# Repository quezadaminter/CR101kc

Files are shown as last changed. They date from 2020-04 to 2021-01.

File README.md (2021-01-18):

# CR101kc
The electrical schematics and PCB layout for the CR101 boards.  

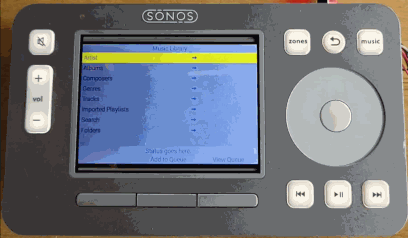
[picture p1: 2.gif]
  

# Firmware  
https://github.com/quezadaminter/CR101fw  

# User code  
https://github.com/quezadaminter/CR101py  

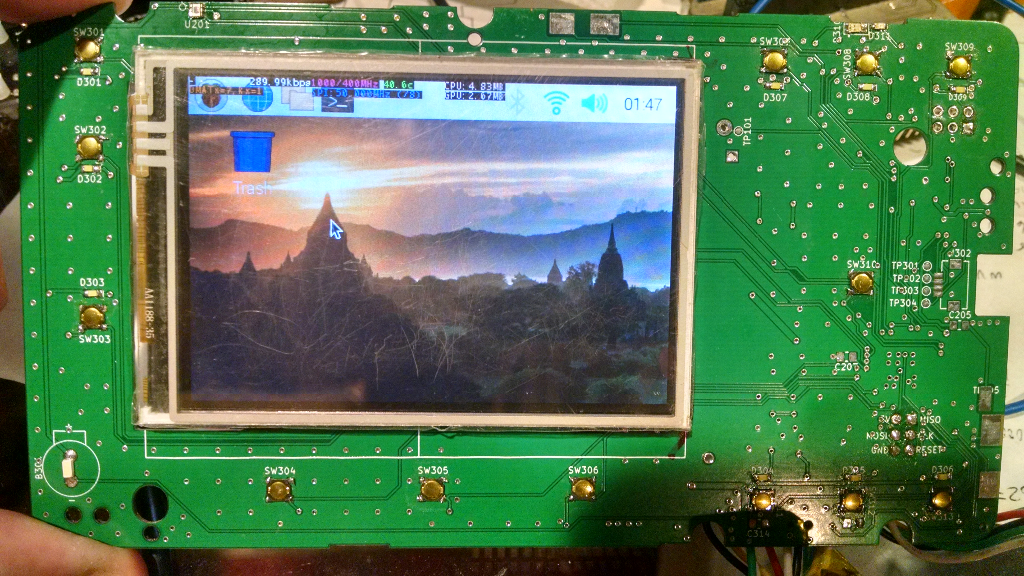
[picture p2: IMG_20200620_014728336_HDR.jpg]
  
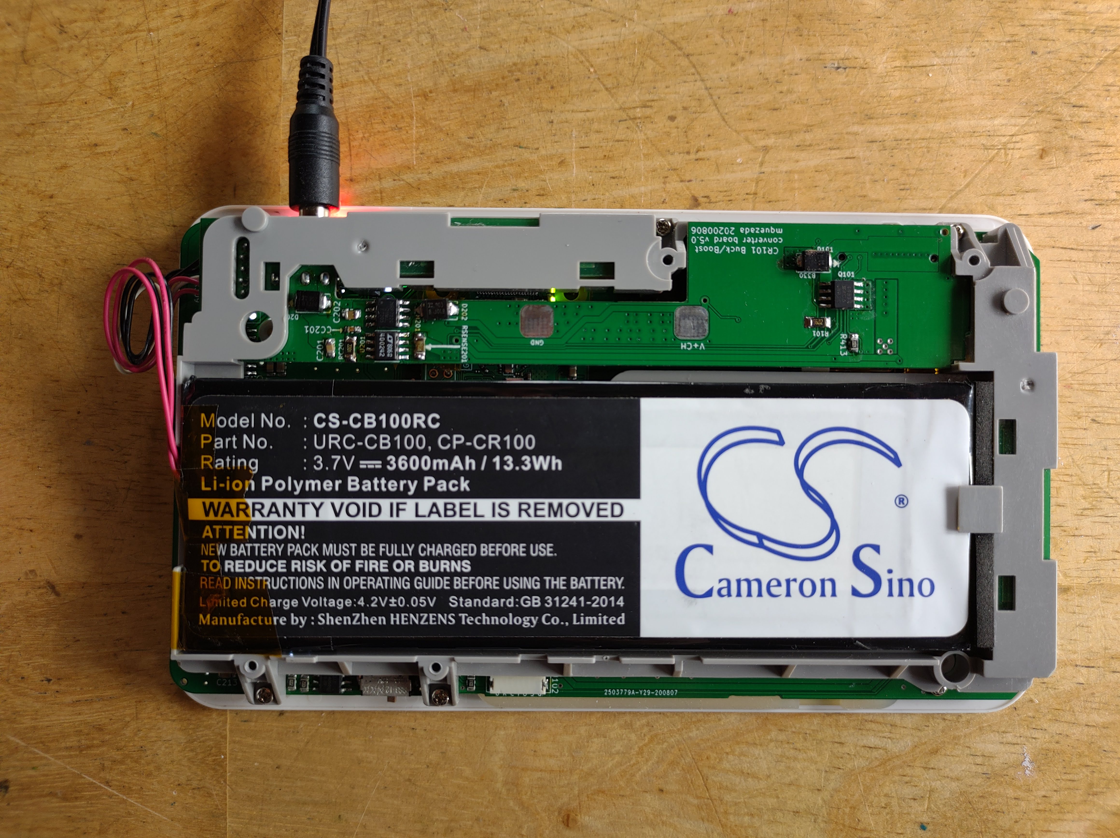
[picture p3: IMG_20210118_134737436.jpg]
  
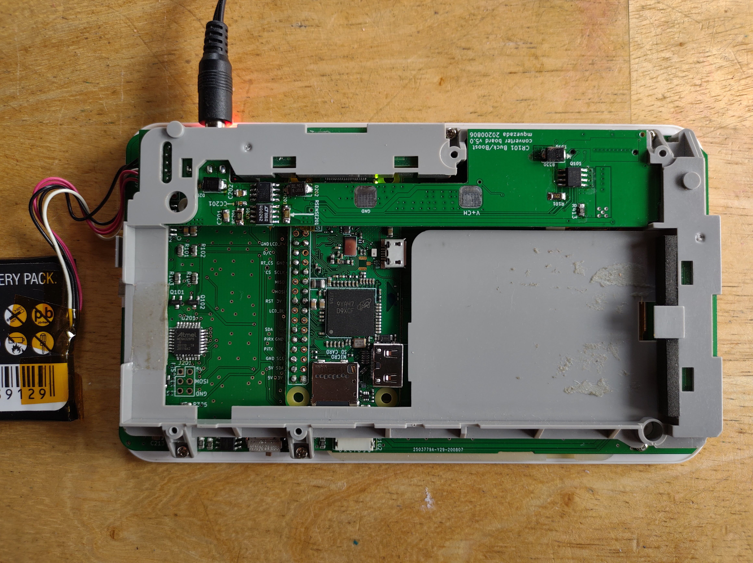
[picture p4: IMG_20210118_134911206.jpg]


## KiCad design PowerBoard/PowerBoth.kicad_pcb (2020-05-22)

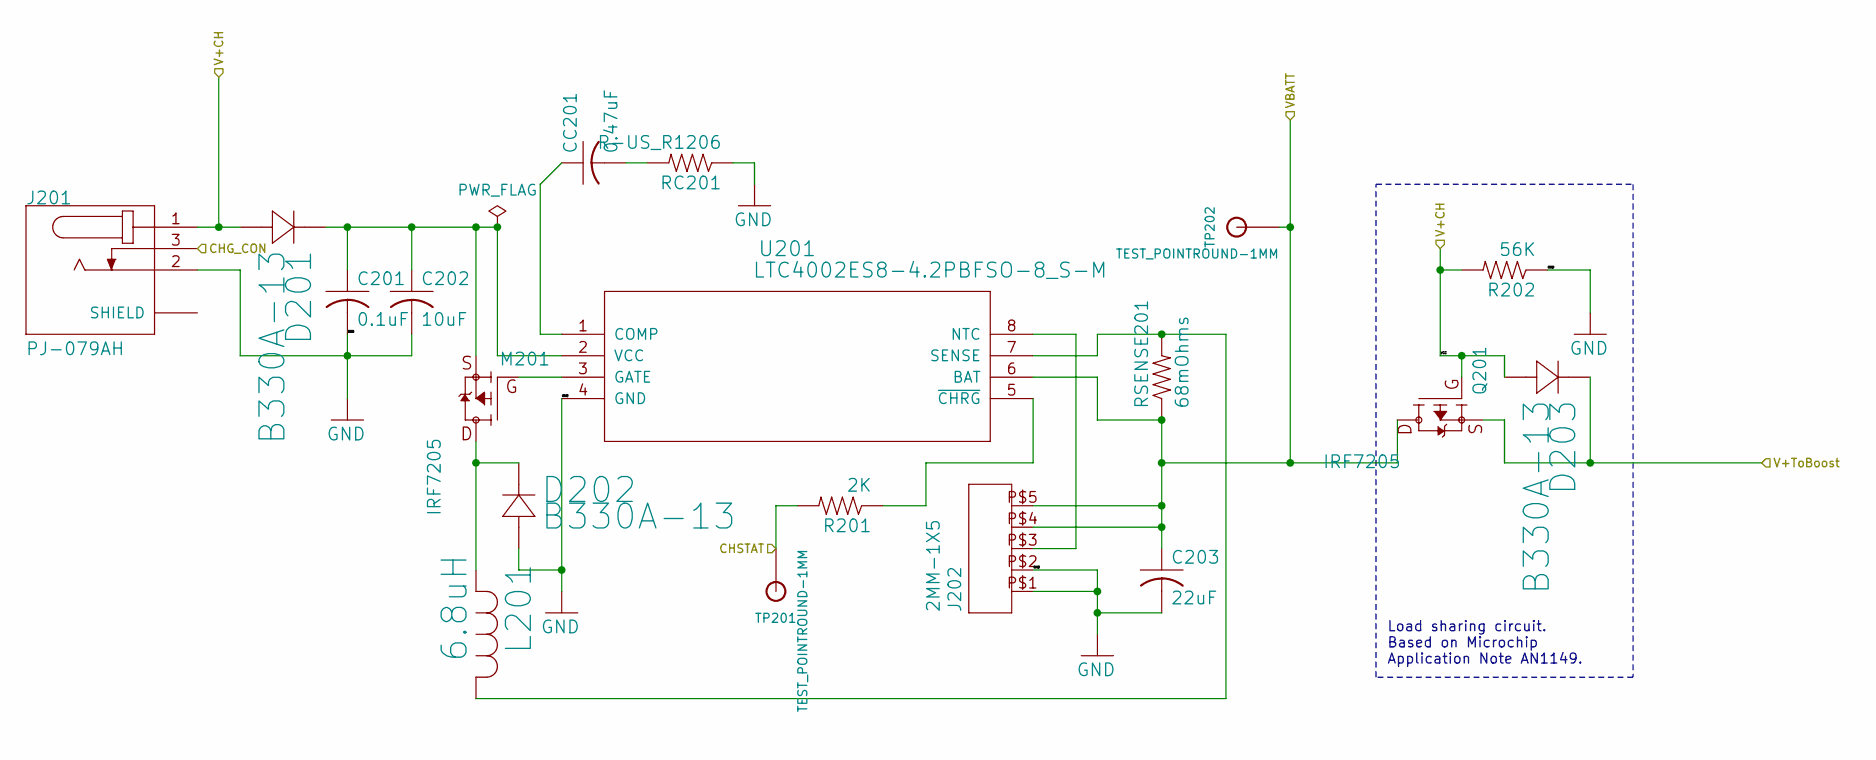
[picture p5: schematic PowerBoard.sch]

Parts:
C201: 0.1uF; C1210; LCSC Part Number 1
C202: 10uF; C1210
C203: 22uF; C1210
CC201: 0.47uF; C0603
D201, D202, D203: B330A-13; SMA-M
J201: PJ-079AH; CUI_PJ-079AH
J202: 2MM-1X5; 2MM_1X5
L201: 6.8uH; IND_B952AS-H-220M=P3
M201: IRF7205; 8SOIC; LCSC Part Number C55419
Q201: IRF7205; 8SOIC; LCSC Part Number C55419
R201: 2K; R1206
R202: 56K; 1206
RC201: R-US_R1206; R1206
RSENSE201: 68mOhms; R1206
TP201, TP202: TEST_POINTROUND-1MM; TEST_POINT_ROUND_1MM
U201: LTC4002ES8-4.2PBFSO-8_S-M; SO-8_S-M

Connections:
/Charger/CHG_CON: J201.3; also elsewhere on the board
/Charger/CHSTAT: R201.2, TP201.1; also elsewhere on the board
/Charger/V+CH: D201.2, D203.2, J201.1, Q201.4 (G), R202.2; also elsewhere on the board
/Charger/V+ToBoost: D203.1, Q201.1 (S), Q201.2 (S), Q201.3 (S); also elsewhere on the board
/Charger/VBATT: C203.1, J202.P$4, J202.P$5, Q201.5 (D), Q201.6 (D), Q201.7 (D), Q201.8 (D), RSENSE201.1, TP202.1, U201.6 (BAT); also elsewhere on the board
GND: C201.2, C202.2, C203.2, D202.2, J201.2, J202.P$1, J202.P$2, R202.1, RC201.1, U201.4 (GND); also elsewhere on the board
unnamed: C201.1, C202.1, D201.1, M201.1 (S), M201.2 (S), M201.3 (S), U201.2 (VCC)
unnamed: CC201.1, U201.1 (COMP)
unnamed: CC201.2, RC201.2
unnamed: D202.1, L201.2, M201.5 (D), M201.6 (D), M201.7 (D), M201.8 (D)
unnamed: J201.S1 (SHIELD), J201.S2 (SHIELD)
unnamed: J202.P$3, U201.8 (NTC)
unnamed: L201.1, RSENSE201.2, U201.7 (SENSE)
unnamed: M201.4 (G), U201.3 (GATE)
unnamed: R201.1, U201.5 (~CHRG)

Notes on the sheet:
Load sharing circuit. Based on Microchip Application Note AN1149.

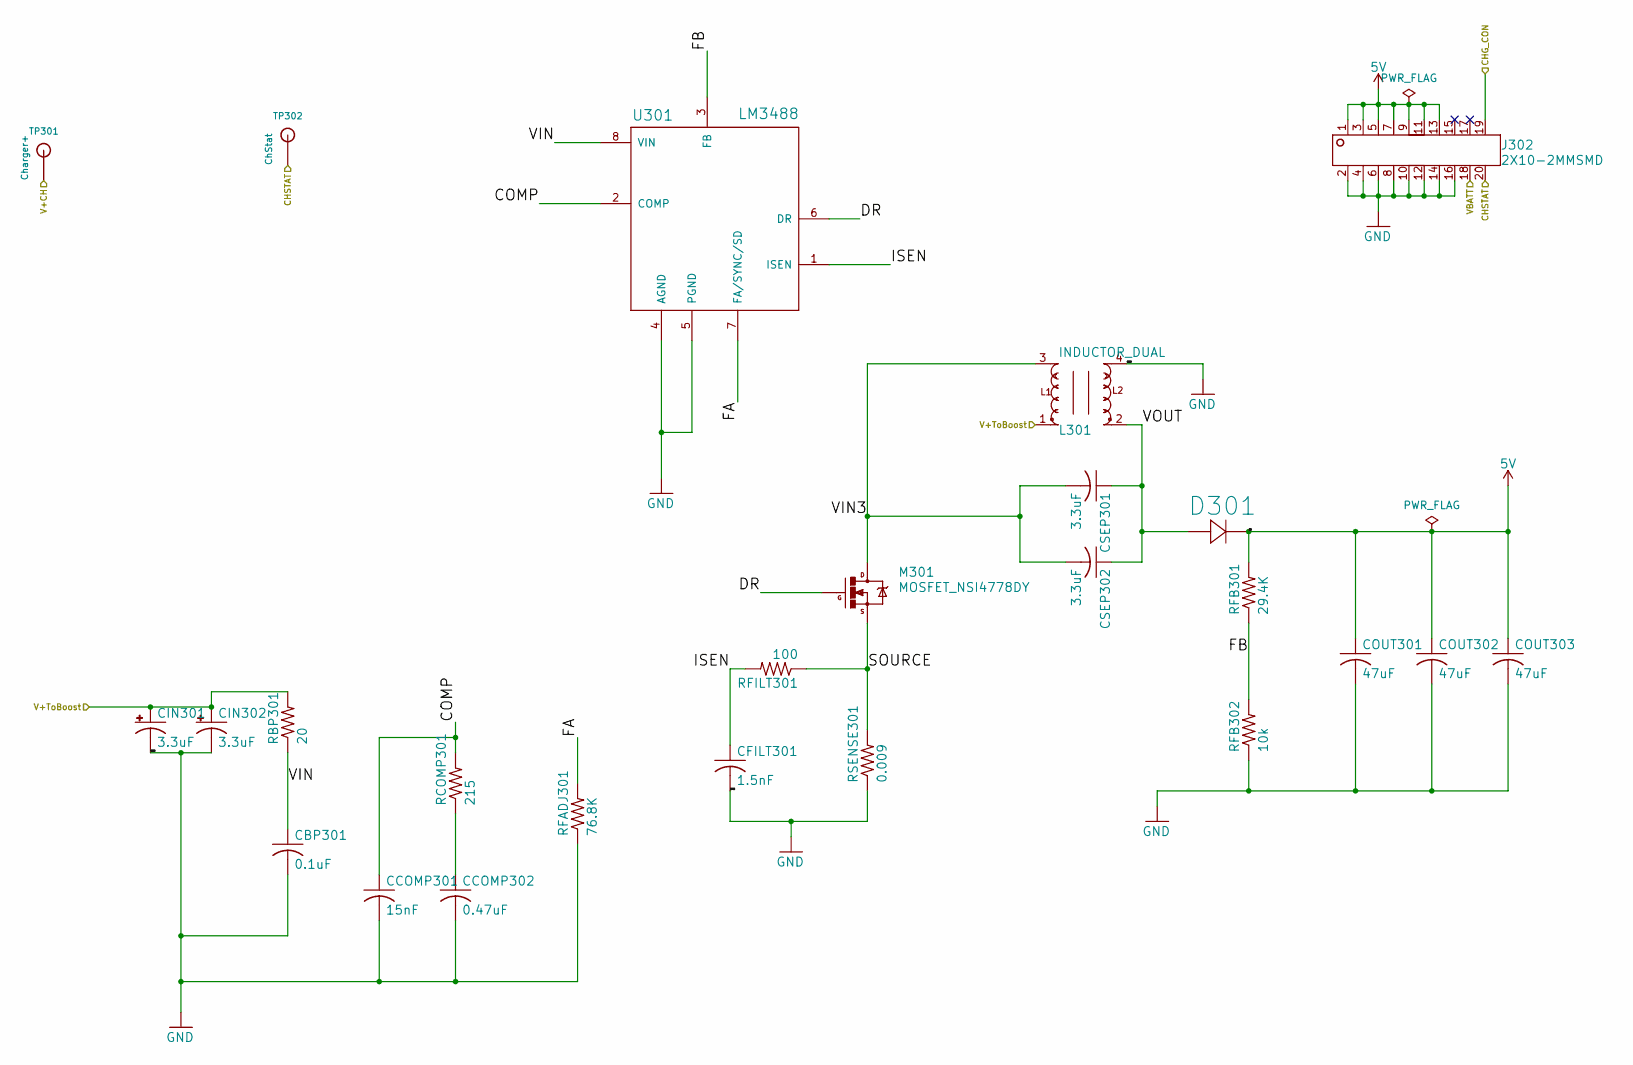
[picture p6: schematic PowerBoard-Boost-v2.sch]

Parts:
CBP301: 0.1uF; C1206
CCOMP301: 15nF; C0805
CCOMP302: 0.47uF; C1206
CFILT301: 1.5nF; C0805
CIN301, CIN302: 3.3uF; 153CLV-0505
COUT301, COUT302, COUT303: 47uF; C1206
CSEP301, CSEP302: 3.3uF; C0805
D301: SL44-E3_57TDIODE_DO214AB-M; DIODE_DO214AB-M
J302: 2X10-2MMSMD; 2X10-2MM
L301: INDUCTOR_DUAL; DRQ125
M301: MOSFET_NSI4778DY; 8SOIC
RBP301: 20; R0805
RCOMP301: 215; R0805
RFADJ301: 76.8K; R0805
RFB301: 29.4K; R1206
RFB302: 10k; R1206
RFILT301: 100; R1206
RSENSE301: 0.009; R1206
TP301: Charger+; TEST_POINT_ROUND_1MM
TP302: ChStat; TEST_POINT_ROUND_1MM
U301: LM3488; DGK8-M

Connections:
5V: COUT301.1, COUT302.1, COUT303.1, D301.1, J302.1, J302.3, J302.5, J302.7, J302.9, J302.11, J302.13, RFB301.2
/Charger/CHG_CON: J302.19; also elsewhere on the board
/Charger/CHSTAT: J302.20, TP302.1; also elsewhere on the board
/Charger/V+CH: TP301.1; also elsewhere on the board
/Charger/V+ToBoost: CIN301.+, CIN302.+, L301.1, RBP301.2; also elsewhere on the board
/Charger/VBATT: J302.18; also elsewhere on the board
/SEPIC Converter/COMP: CCOMP301.1, RCOMP301.2, U301.2 (COMP)
/SEPIC Converter/DR: M301.4 (G), U301.6 (DR)
/SEPIC Converter/FA: RFADJ301.2, U301.7 (FA/SYNC/SD)
/SEPIC Converter/FB: RFB301.1, RFB302.2, U301.3 (FB)
/SEPIC Converter/ISEN: CFILT301.1, RFILT301.2, U301.1 (ISEN)
/SEPIC Converter/SOURCE: M301.1 (S), M301.2 (S), M301.3 (S), RFILT301.1, RSENSE301.2
/SEPIC Converter/VIN: CBP301.1, RBP301.1, U301.8 (VIN)
/SEPIC Converter/VIN3: CSEP301.2, CSEP302.2, L301.3, M301.5 (D), M301.6 (D), M301.7 (D), M301.8 (D)
/SEPIC Converter/VOUT: CSEP301.1, CSEP302.1, D301.2, L301.2
GND: CBP301.2, CCOMP301.2, CCOMP302.2, CFILT301.2, CIN301.-, CIN302.-, COUT301.2, COUT302.2, COUT303.2, J302.2, J302.4, J302.6, J302.8, J302.10, J302.12, J302.14, J302.16, L301.4, RFADJ301.1, RFB302.1, RSENSE301.1, U301.4 (AGND), U301.5 (PGND); also elsewhere on the board
unnamed: CCOMP302.1, RCOMP301.1

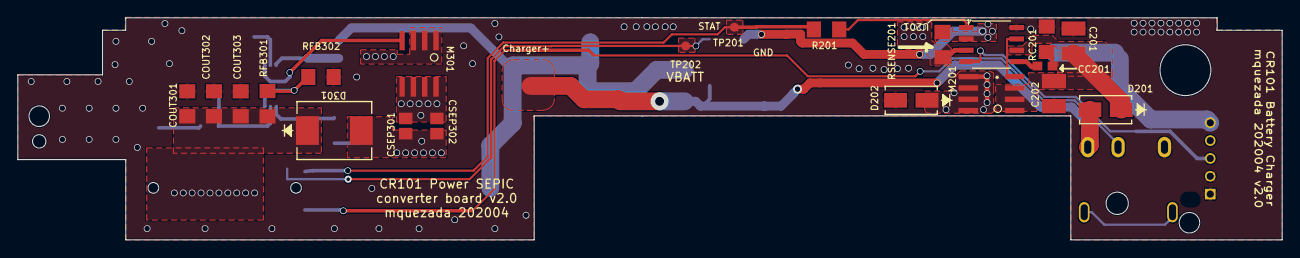
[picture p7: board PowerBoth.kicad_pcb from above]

Board: 2 copper layers, 141.8 x 24.9 mm, 48 parts (0 on the bottom side), 26 nets.

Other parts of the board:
@HOLE0, @HOLE1, @HOLE2, @HOLE3, @HOLE4: (no value)

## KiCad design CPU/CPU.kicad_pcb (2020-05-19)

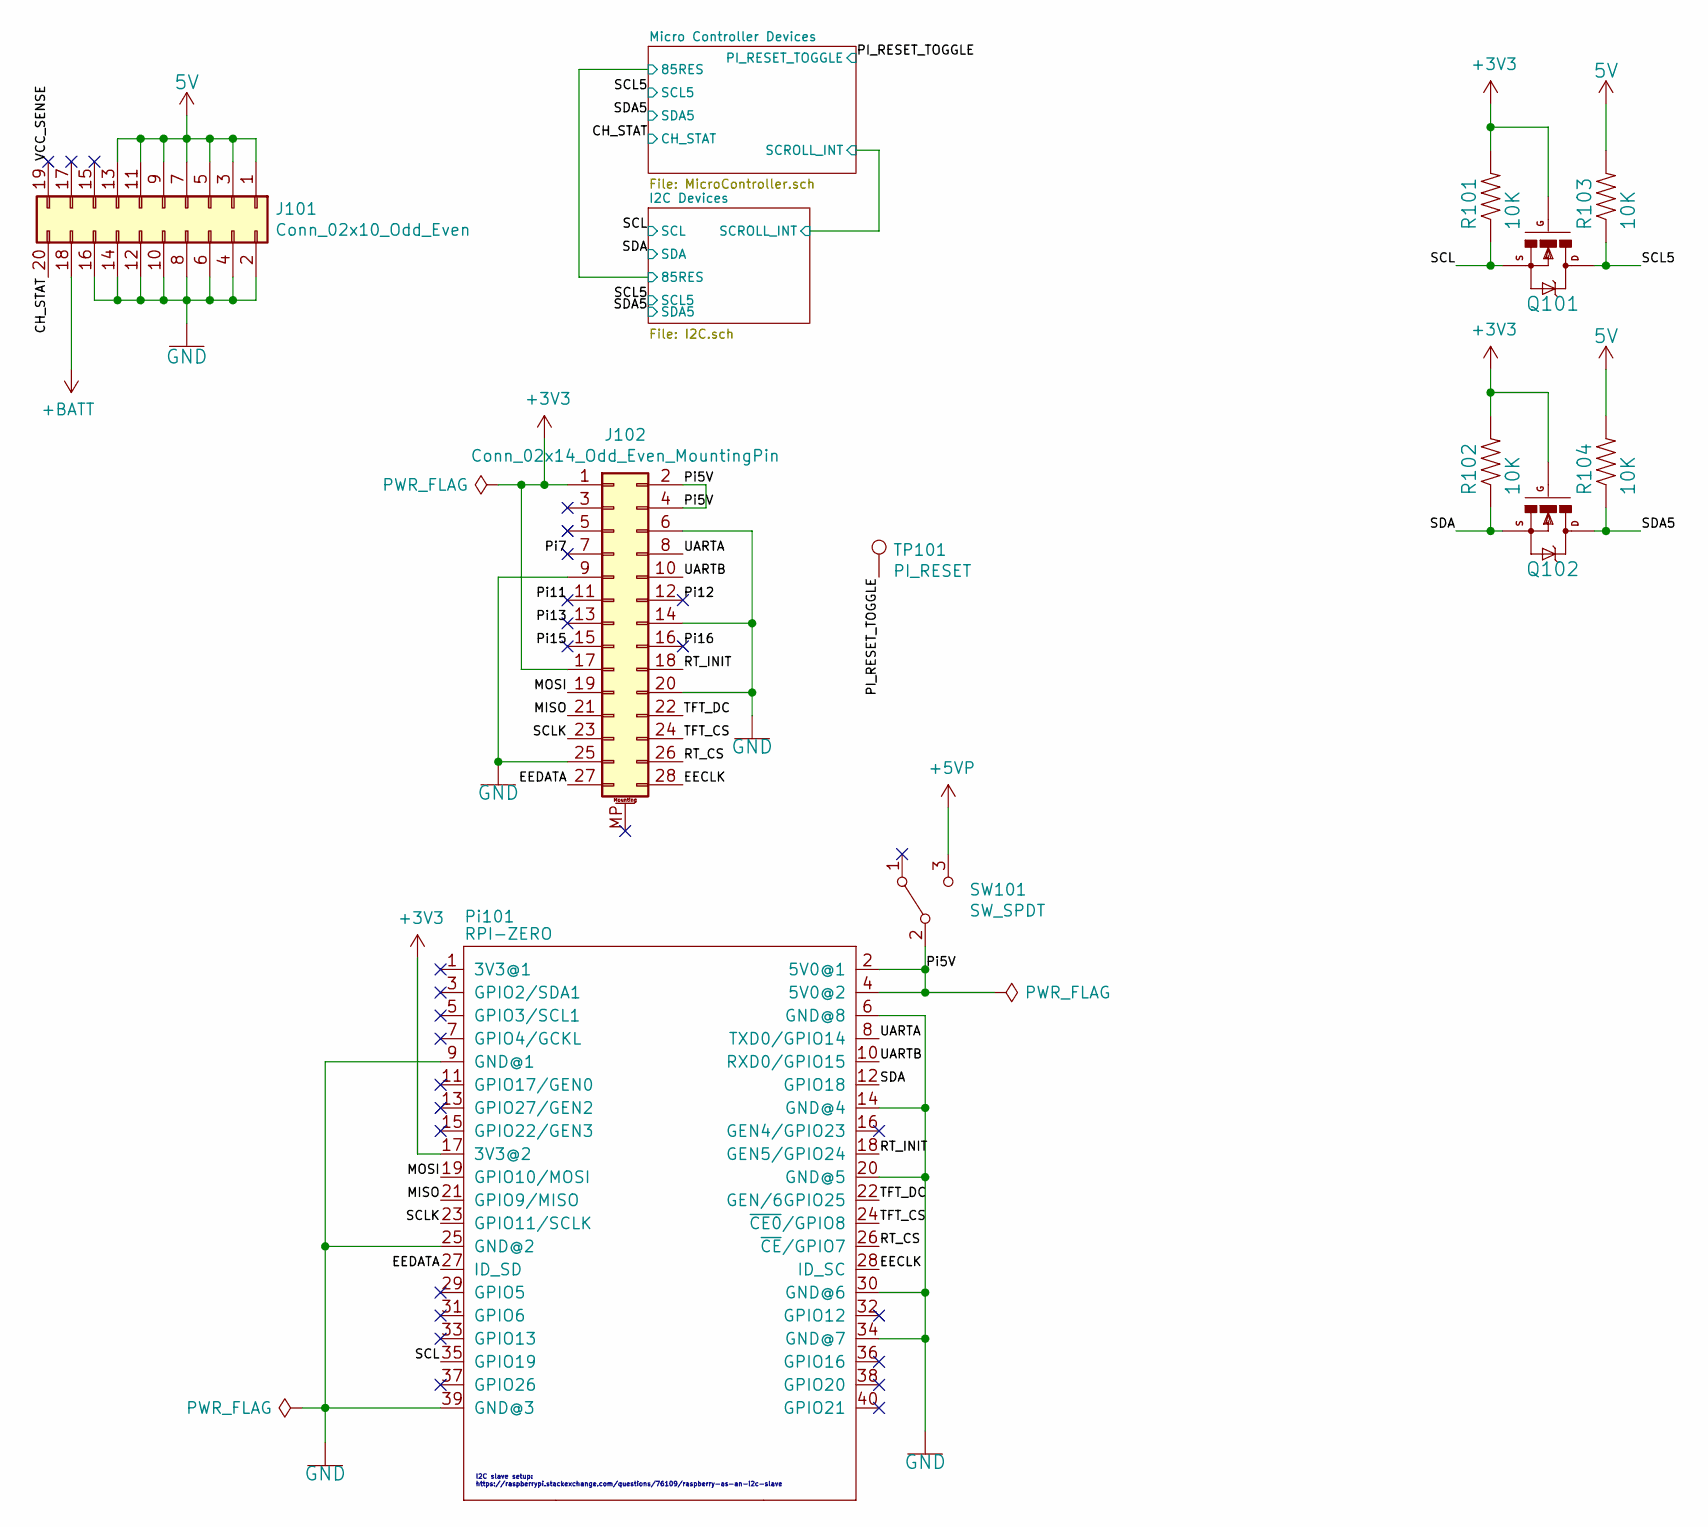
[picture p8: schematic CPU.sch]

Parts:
J101: Conn_02x10_Odd_Even; PinHeader_2x10_P2.00mm_Vertical_SMD; LCSC Part Number C135211
J102: Conn_02x14_Odd_Even_MountingPin; 2X14_SMT_MALE-2
Pi101: RPI-ZERO; RASPBERRYPI_Zero-No_Mounting_Holes_SMD_Flat
Q101, Q102: IRLML0040TR; SOT23; LCSC Part Number C67273
R101, R102, R103, R104: 10K; R_0805_2012Metric_Pad1.15x1.40mm_HandSolder; LCSC Part Number C17414
SW101: SW_SPDT; SWITCH_PCM12SMTR_SPDT; LCSC Part Number C221841
TP101: PI_RESET; TestPoint_Pad_D1.0mm

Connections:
5V: J101.1, J101.3, J101.5, J101.7, J101.9, J101.11, J101.13, R103.2, R104.2; also elsewhere on the board
+3V3: J102.1, J102.17, Pi101.17 (3V3@2), Q101.1 (G), Q102.1 (G), R101.2, R102.2; also elsewhere on the board
+5VP: SW101.3 (C); also elsewhere on the board
+BATT: J101.18; also elsewhere on the board
/CH_STAT: J101.20; also elsewhere on the board
/EECLK: J102.28, Pi101.28 (ID_SC)
/EEDATA: J102.27, Pi101.27 (ID_SD)
/MISO: J102.21, Pi101.21 (GPIO9/MISO)
/MOSI: J102.19, Pi101.19 (GPIO10/MOSI)
/PI_RESET_TOGGLE: TP101.1; also elsewhere on the board
/Pi5V: J102.2, J102.4, Pi101.2 (5V0@1), Pi101.4 (5V0@2), SW101.2 (B)
/Pi7: J102.7
/Pi11: J102.11
/Pi12: J102.12
/Pi13: J102.13
/Pi15: J102.15
/Pi16: J102.16
/RT_CS: J102.26, Pi101.26 (~CE~/GPIO7)
/RT_INIT: J102.18, Pi101.18 (GEN5/GPIO24)
/SCL: Pi101.35 (GPIO19), Q101.2 (S), R101.1; also elsewhere on the board
/SCL5: Q101.3 (D), R103.1; also elsewhere on the board
/SCLK: J102.23, Pi101.23 (GPIO11/SCLK)
/SDA: Pi101.12 (GPIO18), Q102.2 (S), R102.1; also elsewhere on the board
/SDA5: Q102.3 (D), R104.1; also elsewhere on the board
/TFT_CS: J102.24, Pi101.24 (~CE0~/GPIO8)
/TFT_DC: J102.22, Pi101.22 (GEN/6GPIO25)
/UARTA: J102.8, Pi101.8 (TXD0/GPIO14)
/UARTB: J102.10, Pi101.10 (RXD0/GPIO15)
/VCC_SENSE: J101.19
GND: J101.2, J101.4, J101.6, J101.8, J101.10, J101.12, J101.14, J101.16, J102.6, J102.9, J102.14, J102.20, J102.25, Pi101.6 (GND@8), Pi101.9 (GND@1), Pi101.14 (GND@4), Pi101.20 (GND@5), Pi101.25 (GND@2), Pi101.30 (GND@6), Pi101.34 (GND@7), Pi101.39 (GND@3); also elsewhere on the board

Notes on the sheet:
I2C slave setup: https://raspberrypi.stackexchange.com/questions/76109/raspberry-as-an-i2c-slave

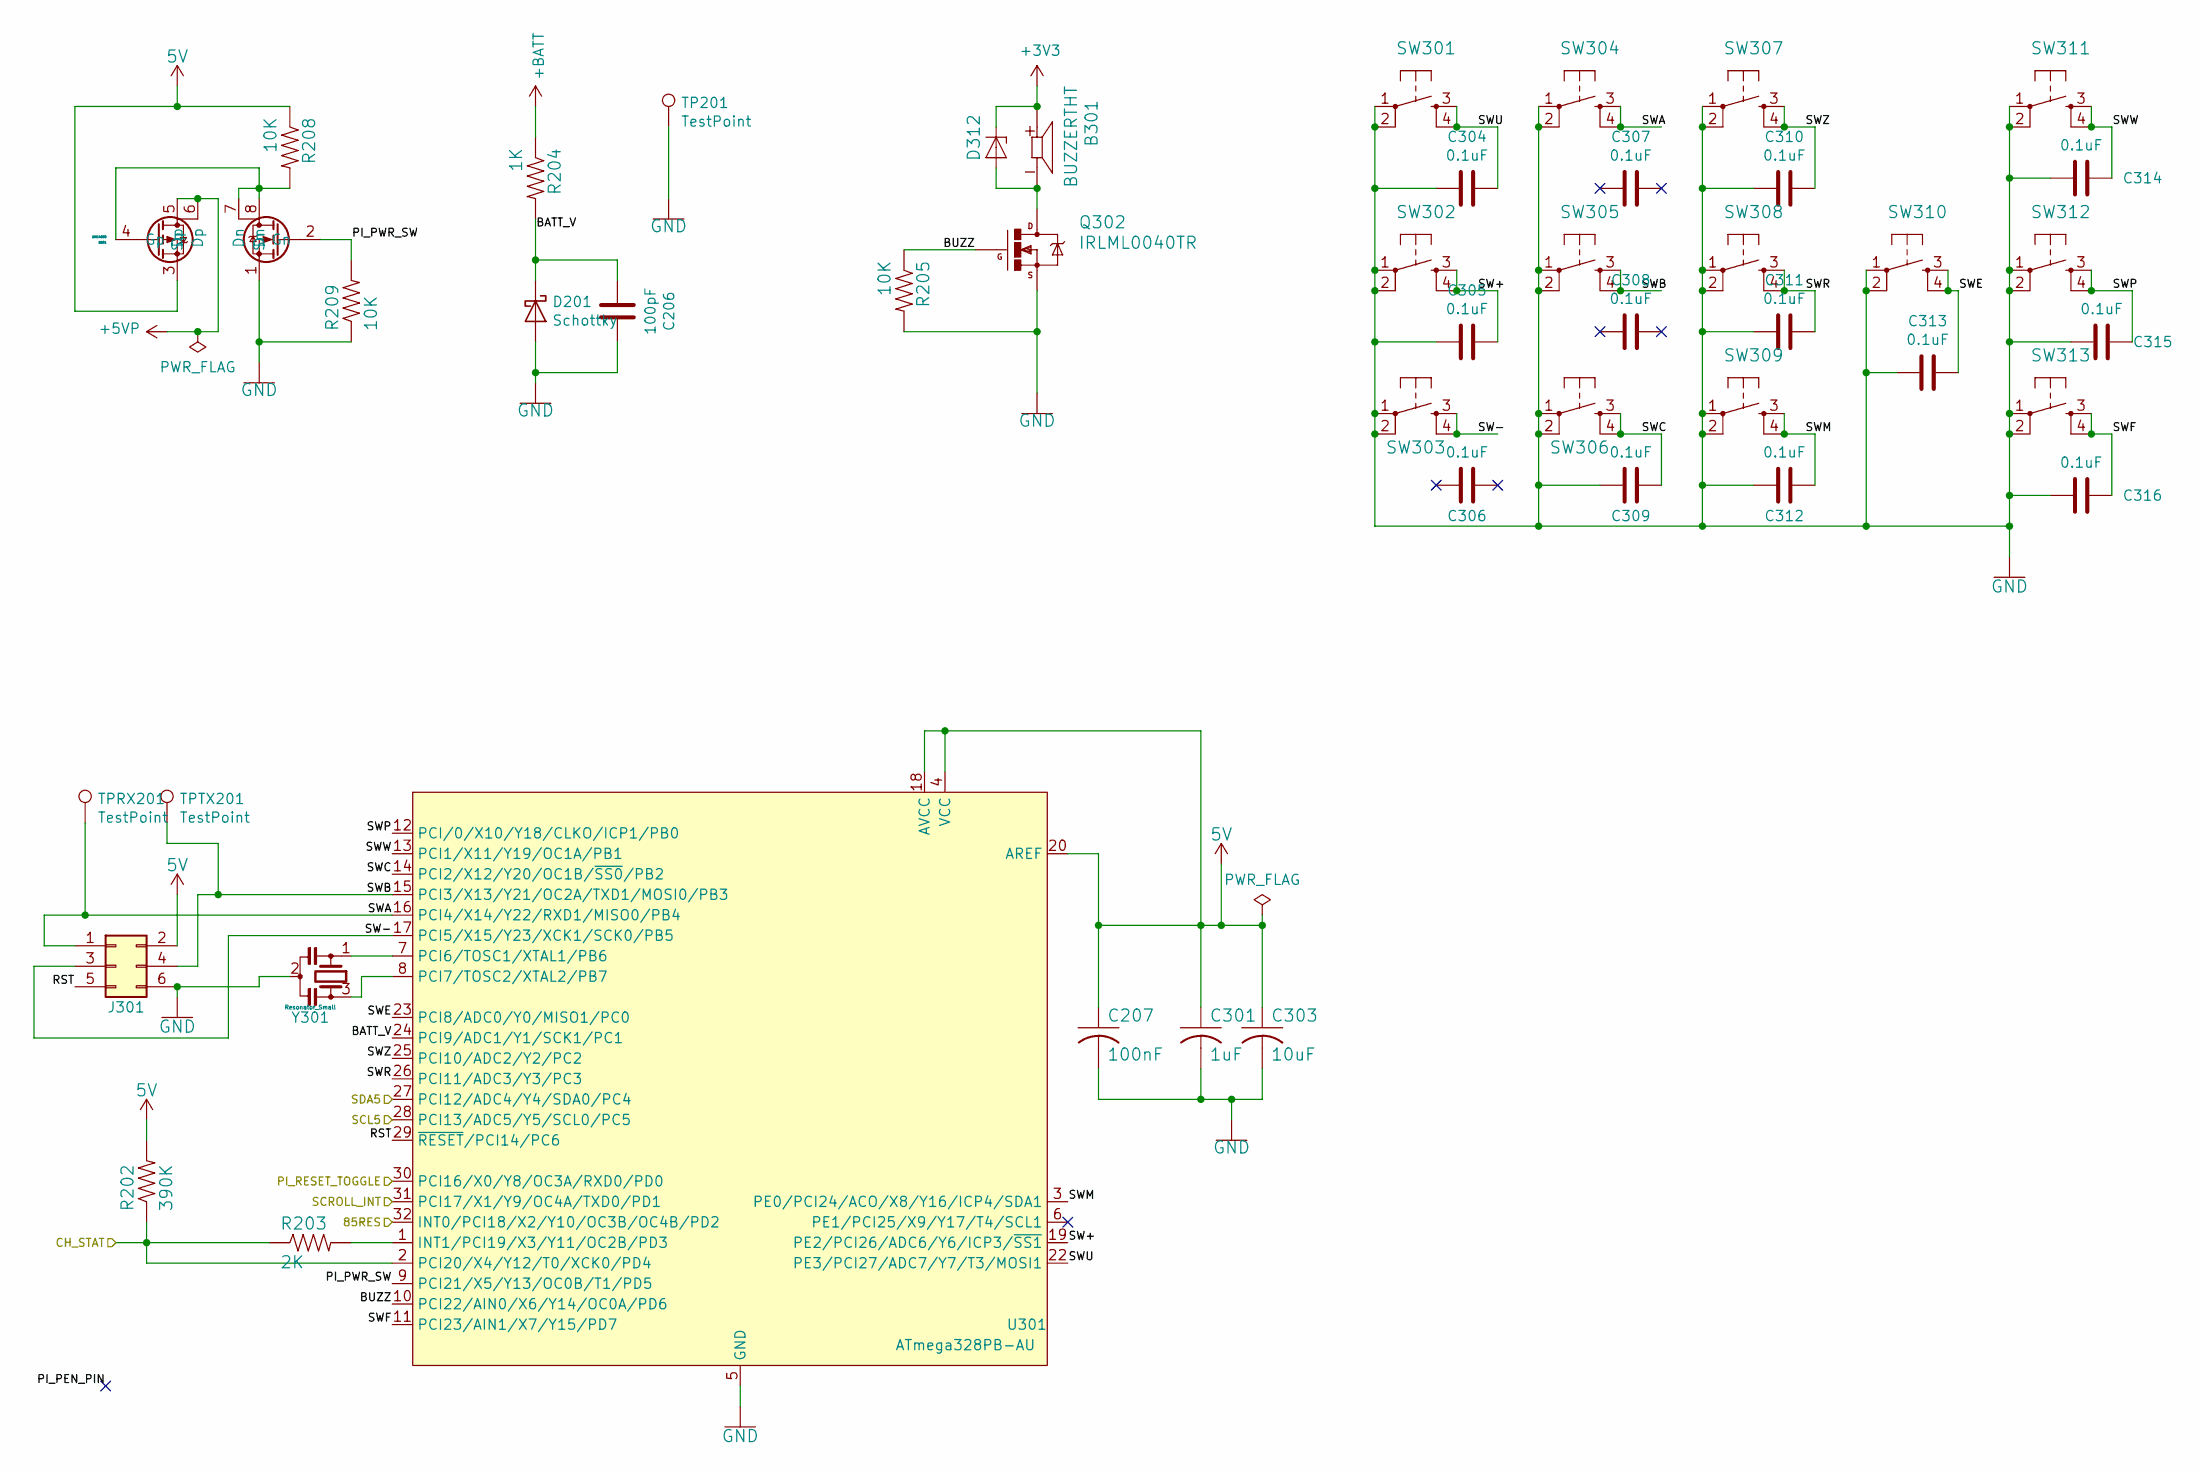
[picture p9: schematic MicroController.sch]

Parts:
B301: BUZZERTHT; XDCR_CMT-0904-85T; DigiKey CMT-0904-85T
C206: 100pF; C_0805_2012Metric_Pad1.15x1.40mm_HandSolder; LCSC Part Number C49678
C207: 100nF; C_0805_2012Metric_Pad1.15x1.40mm_HandSolder; LCSC Part Number C1848
C301: 1uF; C_0805_2012Metric_Pad1.15x1.40mm_HandSolder; LCSC Part Number C28323
C303: 10uF; C_0805_2012Metric_Pad1.15x1.40mm_HandSolder; LCSC Part Number C15850
C304, C305, C306, C307, C308, C309, C310, C311, C312, C313, C314, C315, C316: 0.1uF; C_0805_2012Metric_Pad1.15x1.40mm_HandSolder; LCSC Part Number C49678
D201: Schottky; D_0805_2012Metric_Pad1.15x1.40mm_HandSolder
D312: DIODE; MICRO_SMP; LCSC Part Number C111315
J301: Conn_02x03_Odd_Even; PinHeader_2x03_P2.54mm_Vertical; DigiKey 818-22-006-10-002101, 818-22-006-10-005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
Q201: DMC4050; SO-8_3.9x4.9mm_P1.27mm; DigiKey DMC4050SSD-13
Q302: IRLML0040TR; SOT23; LCSC Part Number C67273
R202: 390K; R_0805_2012Metric_Pad1.15x1.40mm_HandSolder; LCSC Part Number C17656
R203: 2K; R_0805_2012Metric_Pad1.15x1.40mm_HandSolder; LCSC Part Number C17604
R204: 1K; R_0805_2012Metric_Pad1.15x1.40mm_HandSolder; LCSC Part Number C17513
R205, R208, R209: 10K; R_0805_2012Metric_Pad1.15x1.40mm_HandSolder; LCSC Part Number C17414
SW301, SW302, SW303, SW304, SW305, SW306, SW307, SW308, SW309, SW310, SW311, SW312, SW313: TACTILE_SWITCHPTS540-SMD; PTS540-ULTRA_LOW_PROFILE_SW_SPST; LCSC Part Number C221864
TP201: TestPoint; TestPoint_Pad_4.0x4.0mm
TPRX201: TestPoint; TestPoint_Pad_D2.0mm
TPTX201: TestPoint; TestPoint_Pad_D2.0mm
U301: ATmega328PB-AU; TQFP-32_7x7mm_P0.8mm; LCSC Part Number C132230
Y301: Resonator_Small; Resonator_SMD_muRata_CSTxExxV-3Pin_3.0x1.1mm_HandSoldering; DigiKey CSTNE20M0VH3L000R0

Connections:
5V: C207.1, C301.1, C303.1, J301.2, Q201.3 (Sp), R202.2, R208.1, U301.4 (VCC), U301.18 (AVCC), U301.20 (AREF); also elsewhere on the board
+3V3: B301.P, D312.K (C); also elsewhere on the board
+5VP: Q201.5 (Dp), Q201.6 (Dp); also elsewhere on the board
+BATT: R204.1; also elsewhere on the board
/CH_STAT: R202.1, R203.1, U301.2 (PCI20/X4/Y12/T0/XCK0/PD4); also elsewhere on the board
/I2C Devices/85RES: U301.32 (INT0/PCI18/X2/Y10/OC3B/OC4B/PD2)
/I2C Devices/SCROLL_INT: U301.31 (PCI17/X1/Y9/OC4A/TXD0/PD1); also elsewhere on the board
/Micro Controller Devices/BATT_V: C206.1, D201.1 (K), R204.2, U301.24 (PCI9/ADC1/Y1/SCK1/PC1)
/Micro Controller Devices/BUZZ: Q302.1 (G), R205.1, U301.10 (PCI22/AIN0/X6/Y14/OC0A/PD6)
/Micro Controller Devices/PI_PWR_SW: Q201.2 (Gn), R209.2, U301.9 (PCI21/X5/Y13/OC0B/T1/PD5)
/Micro Controller Devices/RST: J301.5, U301.29 (~RESET~/PCI14/PC6)
/Micro Controller Devices/SW+: C305.2, SW302.3, SW302.4, U301.19 (PE2/PCI26/ADC6/Y6/ICP3/~SS1~)
/Micro Controller Devices/SW-: J301.3, SW303.3, SW303.4, U301.17 (PCI5/X15/Y23/XCK1/SCK0/PB5)
/Micro Controller Devices/SWA: J301.1, SW304.3, SW304.4, TPRX201.1, U301.16 (PCI4/X14/Y22/RXD1/MISO0/PB4)
/Micro Controller Devices/SWB: J301.4, SW305.3, SW305.4, TPTX201.1, U301.15 (PCI3/X13/Y21/OC2A/TXD1/MOSI0/PB3)
/Micro Controller Devices/SWC: C309.2, SW306.3, SW306.4, U301.14 (PCI2/X12/Y20/OC1B/~SS0~/PB2)
/Micro Controller Devices/SWE: C313.2, SW310.3, SW310.4, U301.23 (PCI8/ADC0/Y0/MISO1/PC0)
/Micro Controller Devices/SWF: C316.2, SW313.3, SW313.4, U301.11 (PCI23/AIN1/X7/Y15/PD7)
/Micro Controller Devices/SWM: C312.2, SW309.3, SW309.4, U301.3 (PE0/PCI24/ACO/X8/Y16/ICP4/SDA1)
/Micro Controller Devices/SWP: C315.2, SW312.3, SW312.4, U301.12 (PCI/0/X10/Y18/CLKO/ICP1/PB0)
/Micro Controller Devices/SWR: C311.2, SW308.3, SW308.4, U301.26 (PCI11/ADC3/Y3/PC3)
/Micro Controller Devices/SWU: C304.2, SW301.3, SW301.4, U301.22 (PE3/PCI27/ADC7/Y7/T3/MOSI1)
/Micro Controller Devices/SWW: C314.2, SW311.3, SW311.4, U301.13 (PCI1/X11/Y19/OC1A/PB1)
/Micro Controller Devices/SWZ: C310.2, SW307.3, SW307.4, U301.25 (PCI10/ADC2/Y2/PC2)
/PI_RESET_TOGGLE: U301.30 (PCI16/X0/Y8/OC3A/RXD0/PD0); also elsewhere on the board
/SCL5: U301.28 (PCI13/ADC5/Y5/SCL0/PC5); also elsewhere on the board
/SDA5: U301.27 (PCI12/ADC4/Y4/SDA0/PC4); also elsewhere on the board
GND: C206.2, C207.2, C301.2, C303.2, C304.1, C305.1, C309.1, C310.1, C311.1, C312.1, C313.1, C314.1, C315.1, C316.1, D201.2 (A), J301.6, Q201.1 (Sn), Q302.2 (S), R205.2, R209.1, SW301.1, SW301.2, SW302.1, SW302.2, SW303.1, SW303.2, SW304.1, SW304.2, SW305.1, SW305.2, SW306.1, SW306.2, SW307.1, SW307.2, SW308.1, SW308.2, SW309.1, SW309.2, SW310.1, SW310.2, SW311.1, SW311.2, SW312.1, SW312.2, SW313.1, SW313.2, TP201.1, U301.5 (GND), U301.21 (GND), Y301.2; also elsewhere on the board
unnamed: B301.N, D312.A, Q302.3 (D)
unnamed: Q201.4 (Gp), Q201.7 (Dn), Q201.8 (Dn), R208.2
unnamed: R203.2, U301.1 (INT1/PCI19/X3/Y11/OC2B/PD3)
unnamed: U301.7 (PCI6/TOSC1/XTAL1/PB6), Y301.1
unnamed: U301.8 (PCI7/TOSC2/XTAL2/PB7), Y301.3

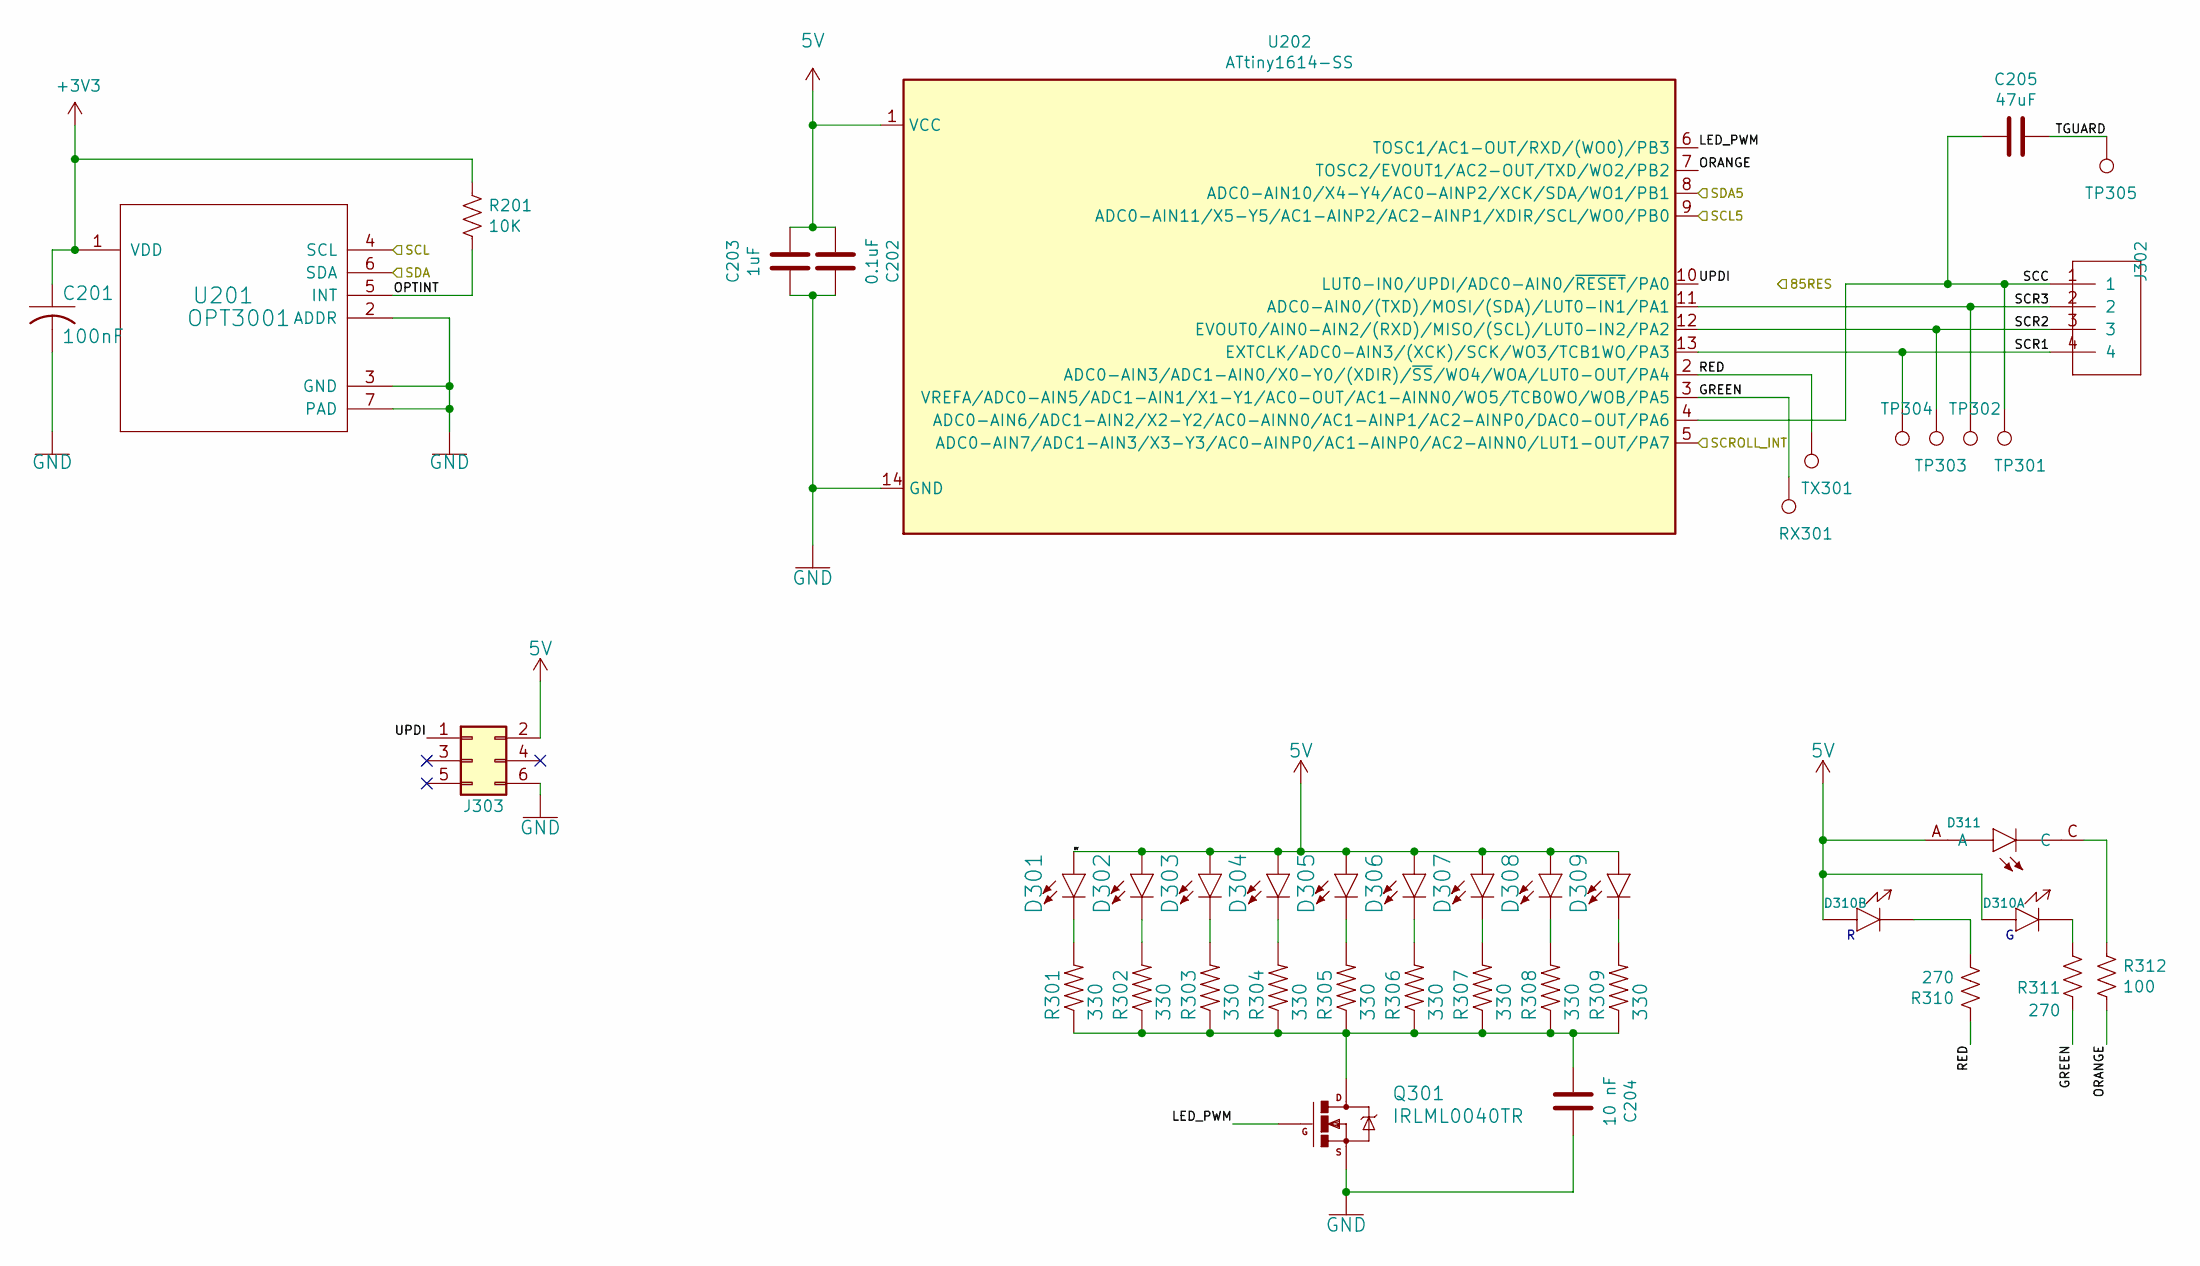
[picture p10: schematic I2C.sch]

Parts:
C201: 100nF; C_0805_2012Metric_Pad1.15x1.40mm_HandSolder; LCSC Part Number C49678
C202: 0.1uF; C_0805_2012Metric_Pad1.15x1.40mm_HandSolder; LCSC Part Number C49678
C203: 1uF; C_0805_2012Metric_Pad1.15x1.40mm_HandSolder; LCSC Part Number C28323
C204: 10 nF; C_0805_2012Metric_Pad1.15x1.40mm_HandSolder; LCSC Part Number C1710
C205: 47uF; C_0805_2012Metric_Pad1.15x1.40mm_HandSolder; LCSC Part Number C28323
D301, D302, D303, D304, D305, D306, D307, D308, D309: LED0603; LED-0603; LCSC Part Number C161619
D310: RG; INOLUX_IN-S85DATRG; LCSC Part Number C391863
D311: 598-8030-107F; LEDSC160X80X70L45N; LCSC Part Number C264422
J302: 1X4SMD-FPC; KYOCERA-6227-FPC_FFC; DigiKey 046227004100829+
J303: Conn_02x03_Odd_Even; PinHeader_2x03_P2.54mm_Vertical; DigiKey 818-22-006-10-002101, 818-22-006-10-005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
Q301: IRLML0040TR; SOT23; LCSC Part Number C67273
R201: 10K; R_0805_2012Metric_Pad1.15x1.40mm_HandSolder; LCSC Part Number C17414
R301, R302, R303, R304, R305, R306, R307, R308, R309: 330; R_0805_2012Metric_Pad1.15x1.40mm_HandSolder; LCSC Part Number C17630
R310, R311: 270; R_0805_2012Metric_Pad1.15x1.40mm_HandSolder; LCSC Part Number C17590
R312: 100; R_0805_2012Metric_Pad1.15x1.40mm_HandSolder; LCSC Part Number C17408
RX301: TestPoint; TestPoint_Pad_D1.0mm; DigiKey ‎709150001040006
TP301: TestPoint; TestPoint_Pad_D1.0mm; DigiKey ‎709150001040006
TP302: TestPoint; TestPoint_Pad_D1.0mm; DigiKey 709150001030006
TP303, TP304, TP305: TestPoint; TestPoint_Pad_D1.0mm
TX301: TestPoint; TestPoint_Pad_D1.0mm; DigiKey ‎709150001040006
U201: OPT3001; DNP0006A; LCSC Part Number C90462
U202: ATtiny1614-SS; SOIC-14_3.9x8.7mm_P1.27mm; LCSC Part Number C141724

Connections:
5V: C202.1, C203.2, D301.A, D302.A, D303.A, D304.A, D305.A, D306.A, D307.A, D308.A, D309.A, D310.2 (A), D310.4 (A), D311.A, J303.2, U202.1 (VCC); also elsewhere on the board
+3V3: C201.1, R201.1, U201.1 (VDD); also elsewhere on the board
/I2C Devices/GREEN: R311.2, RX301.1, U202.3 (VREFA/ADC0-AIN5/ADC1-AIN1/X1-Y1/AC0-OUT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)
/I2C Devices/LED_PWM: Q301.1 (G), U202.6 (TOSC1/AC1-OUT/RXD/(WO0)/PB3)
/I2C Devices/OPTINT: R201.2, U201.5 (INT)
/I2C Devices/ORANGE: R312.2, U202.7 (TOSC2/EVOUT1/AC2-OUT/TXD/WO2/PB2)
/I2C Devices/RED: R310.1, TX301.1, U202.2 (ADC0-AIN3/ADC1-AIN0/X0-Y0/(XDIR)/~SS~/W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)
/I2C Devices/SCC: C205.1, J302.1, TP301.1, U202.4 (ADC0-AIN6/ADC1-AIN2/X2-Y2/AC0-AINN0/AC1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)
/I2C Devices/SCR1: J302.4, TP304.1, U202.13 (EXTCLK/ADC0-AIN3/(XCK)/SCK/WO3/TCB1WO/P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)
/I2C Devices/SCR2: J302.3, TP303.1, U202.12 (EVOUT0/AIN0-AIN2/(RXD)/MISO/(SCL)/LUT0-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)
/I2C Devices/SCR3: J302.2, TP302.1, U202.11 (ADC0-AIN0/(TXD)/MOSI/(SDA)/LUT0-IN1/PA1)
/I2C Devices/SCROLL_INT: U202.5 (ADC0-AIN7/ADC1-AIN3/X3-Y3/AC0-AINP0/AC1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); also elsewhere on the board
/I2C Devices/TGUARD: C205.2, TP305.1
/I2C Devices/UPDI: J303.1, U202.10 (LUT0-IN0/UPDI/ADC0-AIN0/~RESET~/PA0)
/SCL: U201.4 (SCL); also elsewhere on the board
/SCL5: U202.9 (ADC0-AIN11/X5-Y5/AC1-AINP2/AC2-AINP1/XD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); also elsewhere on the board
/SDA: U201.6 (SDA); also elsewhere on the board
/SDA5: U202.8 (ADC0-AIN10/X4-Y4/AC0-AINP2/XCK/SDA/WO1/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); also elsewhere on the board
GND: C201.2, C202.2, C203.1, C204.2, J303.6, Q301.2 (S), U201.2 (ADDR), U201.3 (GND), U201.7 (PAD), U202.14 (GND); also elsewhere on the board
unnamed: C204.1, Q301.3 (D), R301.1, R302.1, R303.1, R304.1, R305.1, R306.1, R307.1, R308.1, R309.1
unnamed: D301.C, R301.2
unnamed: D302.C, R302.2
unnamed: D303.C, R303.2
unnamed: D304.C, R304.2
unnamed: D305.C, R305.2
unnamed: D306.C, R306.2
unnamed: D307.C, R307.2
unnamed: D308.C, R308.2
unnamed: D309.C, R309.2
unnamed: D310.1 (K), R310.2
unnamed: D310.3 (K), R311.1
unnamed: D311.C, R312.1

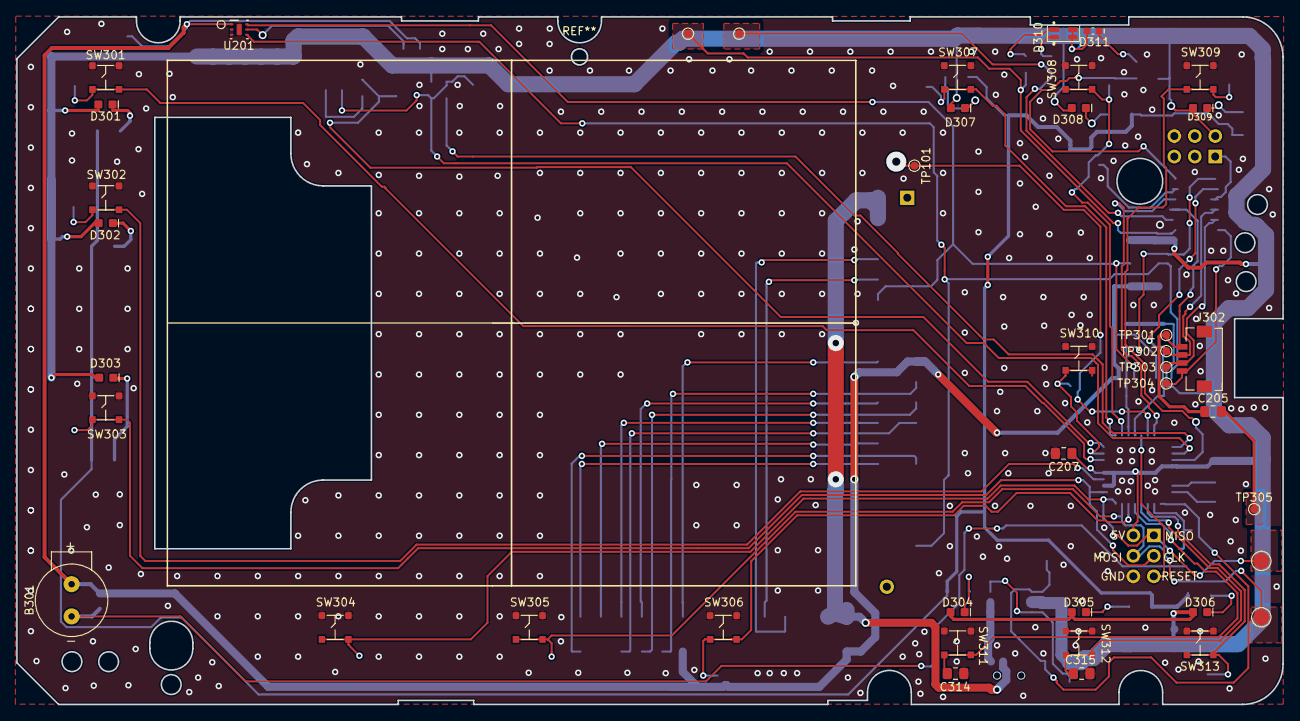
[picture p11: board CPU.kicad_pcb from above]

Board: 2 copper layers, 157.1 x 85.3 mm, 99 parts (0 on the bottom side), 70 nets.

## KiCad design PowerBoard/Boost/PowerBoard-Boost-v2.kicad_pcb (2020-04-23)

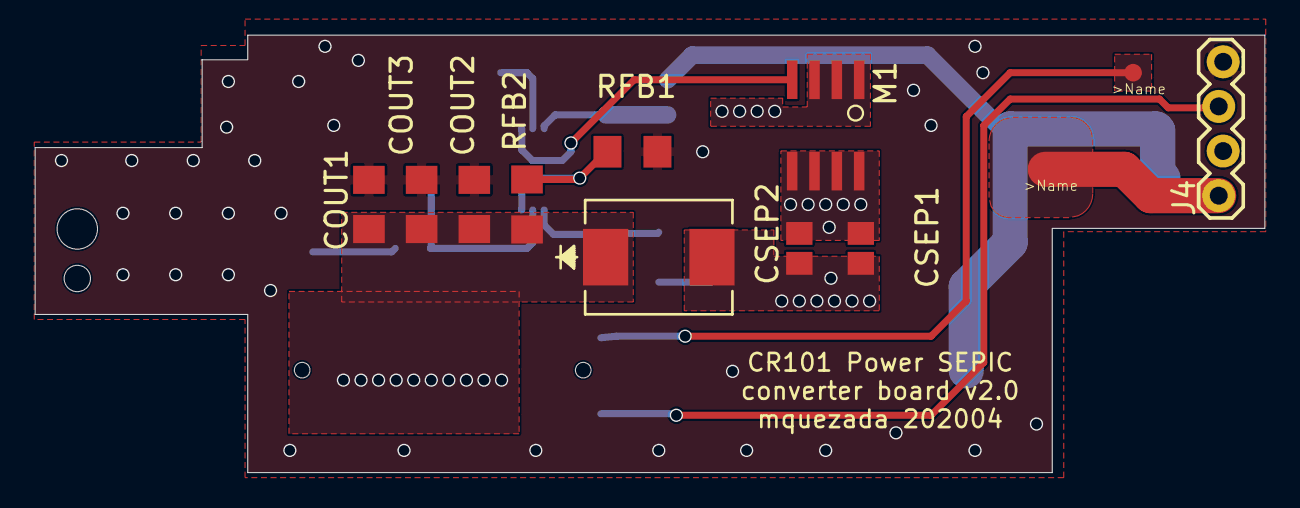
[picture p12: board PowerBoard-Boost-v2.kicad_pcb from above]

Board: 2 copper layers, 70.0 x 24.9 mm, 28 parts (0 on the bottom side), 16 nets.

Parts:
@HOLE0, @HOLE1: (no value)
CBP1: 0.1uF; C1206
CCOMP1: 0.47uF; C1206
CCOMP2: 15nF; C0805
CFILT1: 1.5nF; C0805
CIN1, CIN2: 3.3uF; 153CLV-0505
COUT1, COUT2, COUT3: 47uF; C1206
CSEP1, CSEP2: 3.3uF; C0805
D1: SL44-E3_57TDIODE_DO214AB-M; DIODE_DO214AB-M
J1: 2X10-2MMSMD; 2X10-2MM
J4: CONN_04LOCK; 1X04_LOCK
L1: INDUCTOR_DUAL; DRQ125
M1: MOSFET_NSI4778DY; 8SOIC
RBP1: 20; R0805
RCOMP1: 215; R0805
RFADJ1: 76.8K; R0805
RFB1: 10k; R1206
RFB2: 29.4K; R1206
RFILT1: 100; R1206
RSENSE1: 0.009; R1206
TP1: Charger+; TEST_POINT_ROUND_1MM
TP2: STAT; TEST_POINT_ROUND_1MM
U1: LM3488QMM_NOPBDGK8-M; DGK8-M

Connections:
5V: COUT1.1, COUT2.1, COUT3.1, D1.1, J1.1, J1.3, J1.5, J1.7, J1.9, J1.11, J1.13, RFB2.2
/PowerBoard-Boost-v2_1/BB: CIN1.+, CIN2.+, J4.2, L1.1, RBP1.2
/PowerBoard-Boost-v2_1/COMP: CCOMP2.1, RCOMP1.2, U1.2
/PowerBoard-Boost-v2_1/DR: M1.4, U1.6
/PowerBoard-Boost-v2_1/FA: RFADJ1.2, U1.7
/PowerBoard-Boost-v2_1/FB: RFB1.2, RFB2.1, U1.3
/PowerBoard-Boost-v2_1/ISEN: CFILT1.1, RFILT1.2, U1.1
/PowerBoard-Boost-v2_1/SOURCE: M1.1, M1.2, M1.3, RFILT1.1, RSENSE1.2
/PowerBoard-Boost-v2_1/STAT: J1.20, TP2.1
/PowerBoard-Boost-v2_1/VCC_SENSE: J1.19, J4.3
/PowerBoard-Boost-v2_1/VIN: CBP1.1, RBP1.1, U1.8
/PowerBoard-Boost-v2_1/VIN3: CSEP1.2, CSEP2.2, L1.3, M1.5, M1.6, M1.7, M1.8
/PowerBoard-Boost-v2_1/VOUT: CSEP1.1, CSEP2.1, D1.2, L1.2
GND: CBP1.2, CCOMP1.2, CCOMP2.2, CFILT1.2, CIN1.-, CIN2.-, COUT1.2, COUT2.2, COUT3.2, J1.2, J1.4, J1.6, J1.8, J1.10, J1.12, J1.14, J1.16, J4.4, L1.4, RFADJ1.1, RFB1.1, RSENSE1.1, U1.4, U1.5
unnamed: CCOMP1.1, RCOMP1.1
VCC: J4.1, TP1.1

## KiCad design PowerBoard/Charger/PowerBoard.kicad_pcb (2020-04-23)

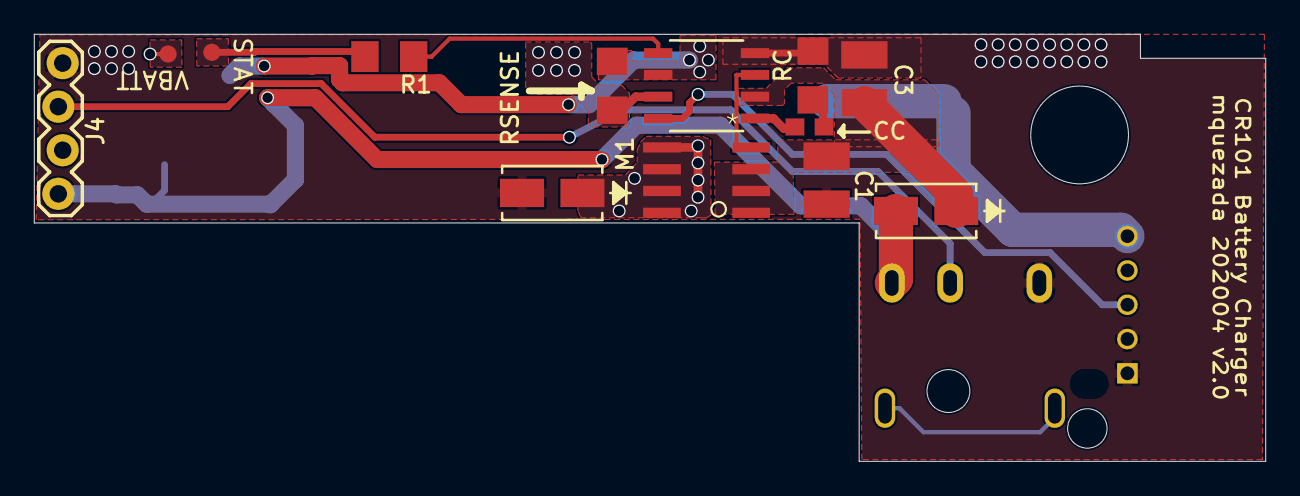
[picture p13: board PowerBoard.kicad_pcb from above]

Board: 2 copper layers, 71.8 x 24.9 mm, 23 parts (0 on the bottom side), 15 nets.

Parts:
@HOLE0, @HOLE1, @HOLE2: (no value)
C1: 10uF; C1210
C2: 22uF; C1210
C3: 0.1uF; C1210
CC: 0.47uF; C0603
D1, D2, D3: B330A-13; SMA-M
J1: 2MM-1X5; 2MM_1X5
J2: PJ-079AH; CUI_PJ-079AH
J4: CONN_04LOCK; 1X04_LOCK
L1: 6.8uH; IND_B952AS-H-220M=P3
M1: IRF7205; 8SOIC
Q10: IRF7205; 8SOIC
R1: 2K; R1206
R47: 56K; 1206
RC: R-US_R1206; R1206
RSENSE: 68mOhms; R1206
TP1-STAT101: TEST_POINTROUND-1MM; TEST_POINT_ROUND_1MM
U1: LTC4002ES8-4.2PBFSO-8_S-M; SO-8_S-M
VBATT: TEST_POINTROUND-1MM; TEST_POINT_ROUND_1MM

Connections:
/STAT: R1.2, TP1-STAT101.1
/VCC_SENSE: J2.3, J4.3
GND: C1.2, C2.2, C3.2, D2.2, J1.P$1, J1.P$2, J2.2, J4.4, R47.1, RC.1, U1.4
unnamed: C1.1, C3.1, D1.1, M1.1, M1.2, M1.3, U1.2
unnamed: CC.1, U1.1
unnamed: CC.2, RC.2
unnamed: D2.1, L1.2, M1.5, M1.6, M1.7, M1.8
unnamed: D3.1, J4.2, Q10.1, Q10.2, Q10.3
unnamed: J1.P$3, U1.8
unnamed: J2.S1, J2.S2
unnamed: L1.1, RSENSE.2, U1.7
unnamed: M1.4, U1.3
unnamed: R1.1, U1.5
VCC: D1.2, D3.2, J2.1, J4.1, Q10.4, R47.2
V_BATT: C2.1, J1.P$4, J1.P$5, Q10.5, Q10.6, Q10.7, Q10.8, RSENSE.1, U1.6, VBATT.1

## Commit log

2020-04-12 Version 1.0 sent to fabrication 20200411.
    [CPU-B_Mask.gbs, CPU-B_Paste.gbp, CPU-B_SilkS.gbo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]
2020-04-21 Last version before switching to resistive model to read the scroll wheel.
    [CPU.kicad_pcb, CPU.sch, I2C.sch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]
2020-04-23 Version 2, DRC and ERC clear, ready to send, waiting on V1 to see what did not work.
    [CPU.kicad_pcb, CPU.sch, I2C.sch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]
2020-04-23 Moved CPU to separate directory in preparation for adding the power board project to the repository.
    [CPU-B_Mask.gbs, CPU-B_Paste.gbp, CPU-B_SilkS.gbo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]
2020-04-23 Adding the power board project to the repository.
    [PowerBoard.kicad_pcb, PowerBoard.sch]
2020-04-23 Replacing old power board with PowerBoth.
    [PowerBoard-Boost-v2.kicad_pcb, PowerBoard-Boost-v2.sch, PowerBoard-Boost-v2_1.sch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]
2020-04-23 Added the remaining 3D models to the components. Not all are quite accurate but good for visualization. Credit for the RPiWZ 3D model goes to Kevin Schneider at https://gallery.autodesk.com/fusion360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
    [CPU.kicad_pcb, MicroController.sch]
2020-05-01 Before correcting the PCB geometry.
    [CPU.kicad_pcb]
2020-05-01 Fixed the PCB outlines so they are at the correct angles.
    [CPU.kicad_pcb]
2020-05-03 Corrected the issues with v1 of the CPU board. Moved to 0.8mm board. Should be ready for another order.
    [CPU.kicad_pcb, CPU.sch, I2C.sch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]
2020-05-07 Rewiring the T84 to the 5 volt line.
    [CPU.kicad_pcb, CPU.sch, I2C.sch]
2020-05-11 Moving signals to accomodate charger sensing.
    [I2C.sch, MicroController.sch]
2020-05-19 Updates from CPU v1 were completed. Switched out Tiny84 for a tiny1614 because the 84 lacks a hardware twi driver. This version was sent to production at jlcpcb.
    [CPU-B_Mask.gbs, CPU-B_Paste.gbp, CPU-B_SilkS.gbo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]
2020-05-19 Cleanup to assemble the power board V2.
    [PowerBoard-Boost-v2.sch, PowerBoard.sch]
2020-05-19 Cleanup to assist the fabricator.
    [CPU.kicad_pcb]
2020-05-22 Switch connector model. Reduce silk screen text size.
    [PowerBoth.kicad_pcb]
2021-01-18 Add files via upload
    Images of boards.
